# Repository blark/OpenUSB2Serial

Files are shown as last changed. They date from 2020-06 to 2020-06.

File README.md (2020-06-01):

# OpenUSB2Serial

An open source USB to serial adapter based on the cheap CH340C IC.

You can get 3 of these boards [from Oshpark](https://oshpark.com/shared_projects/jZ18QKPG) for $5.35.

## BOM

The BOM is [here](/bom.csv) all passives are 805.

Sourcing parts:  
[USB-C connector](https://lcsc.com/product-detail/USB-Type-C_Korean-Hroparts-Elec-TYPE-C-31-M-12_C165948.html)  
[CH340C](https://lcsc.com/product-detail/USB-ICs_WCH-Jiangsu-Qin-Heng-CH340C_C84681.html)  
[AZ1117-3.3](https://lcsc.com/product-detail/Low-Dropout-Regulators-LDO_Diodes-Incorporated-AZ1117CH-3-3TRG1_C92102.html)

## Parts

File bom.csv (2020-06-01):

Ref | Qnty | Value | Cmp name | Footprint | Description | Vendor
C1, C3, | 2 | 0.1uF | C_Small | Capacitor_SMD:C_0805_2012Metric | Unpolarized capacitor, small symbol
C2, C5, | 2 | 10uF | C_Small | Capacitor_SMD:C_0805_2012Metric | Unpolarized capacitor, small symbol
C4, | 1 | 22uF | C_Small | Capacitor_SMD:C_0805_2012Metric | Unpolarized capacitor, small symbol
C6, | 1 | 10nF | C_Small | Capacitor_SMD:C_0805_2012Metric | Unpolarized capacitor, small symbol
J1, | 1 | SERIAL | Conn_01x07 | Connector_PinHeader_2.54mm:PinHeader_1x07_P2.54mm_Vertical | Generic connector, single row, 01x07, script generated (kicad-library-utils/schlib/autogen/connector/)
J2, | 1 | USB_C_Receptacle_USB2.0 | USB_C_Receptacle_USB2.0 | Connector_USB:USB_C_Receptacle_HRO_TYPE-C-31-M-12 | USB 2.0-only Type-C Receptacle connector
JP1, | 1 | VSEL | SolderJumper_3_Open | Jumper:SolderJumper-3_P2.0mm_Open_TrianglePad1.0x1.5mm | Solder Jumper, 3-pole, open
R1, R2, | 2 | 5.1k | R_Small | Resistor_SMD:R_0805_2012Metric | Resistor, small symbol
U1, | 1 | CH340C | CH340G | Package_SO:SOIC-16_3.9x9.9mm_P1.27mm | USB serial converter, UART, SOIC-16
U2, | 1 | AZ1117-3.3 | AZ1117-3.3 | Package_TO_SOT_SMD:SOT-223 | 1A 20V Fixed LDO Linear Regulator, 3.3V, SOT-89/SOT-223/TO-220/TO-252/TO-263

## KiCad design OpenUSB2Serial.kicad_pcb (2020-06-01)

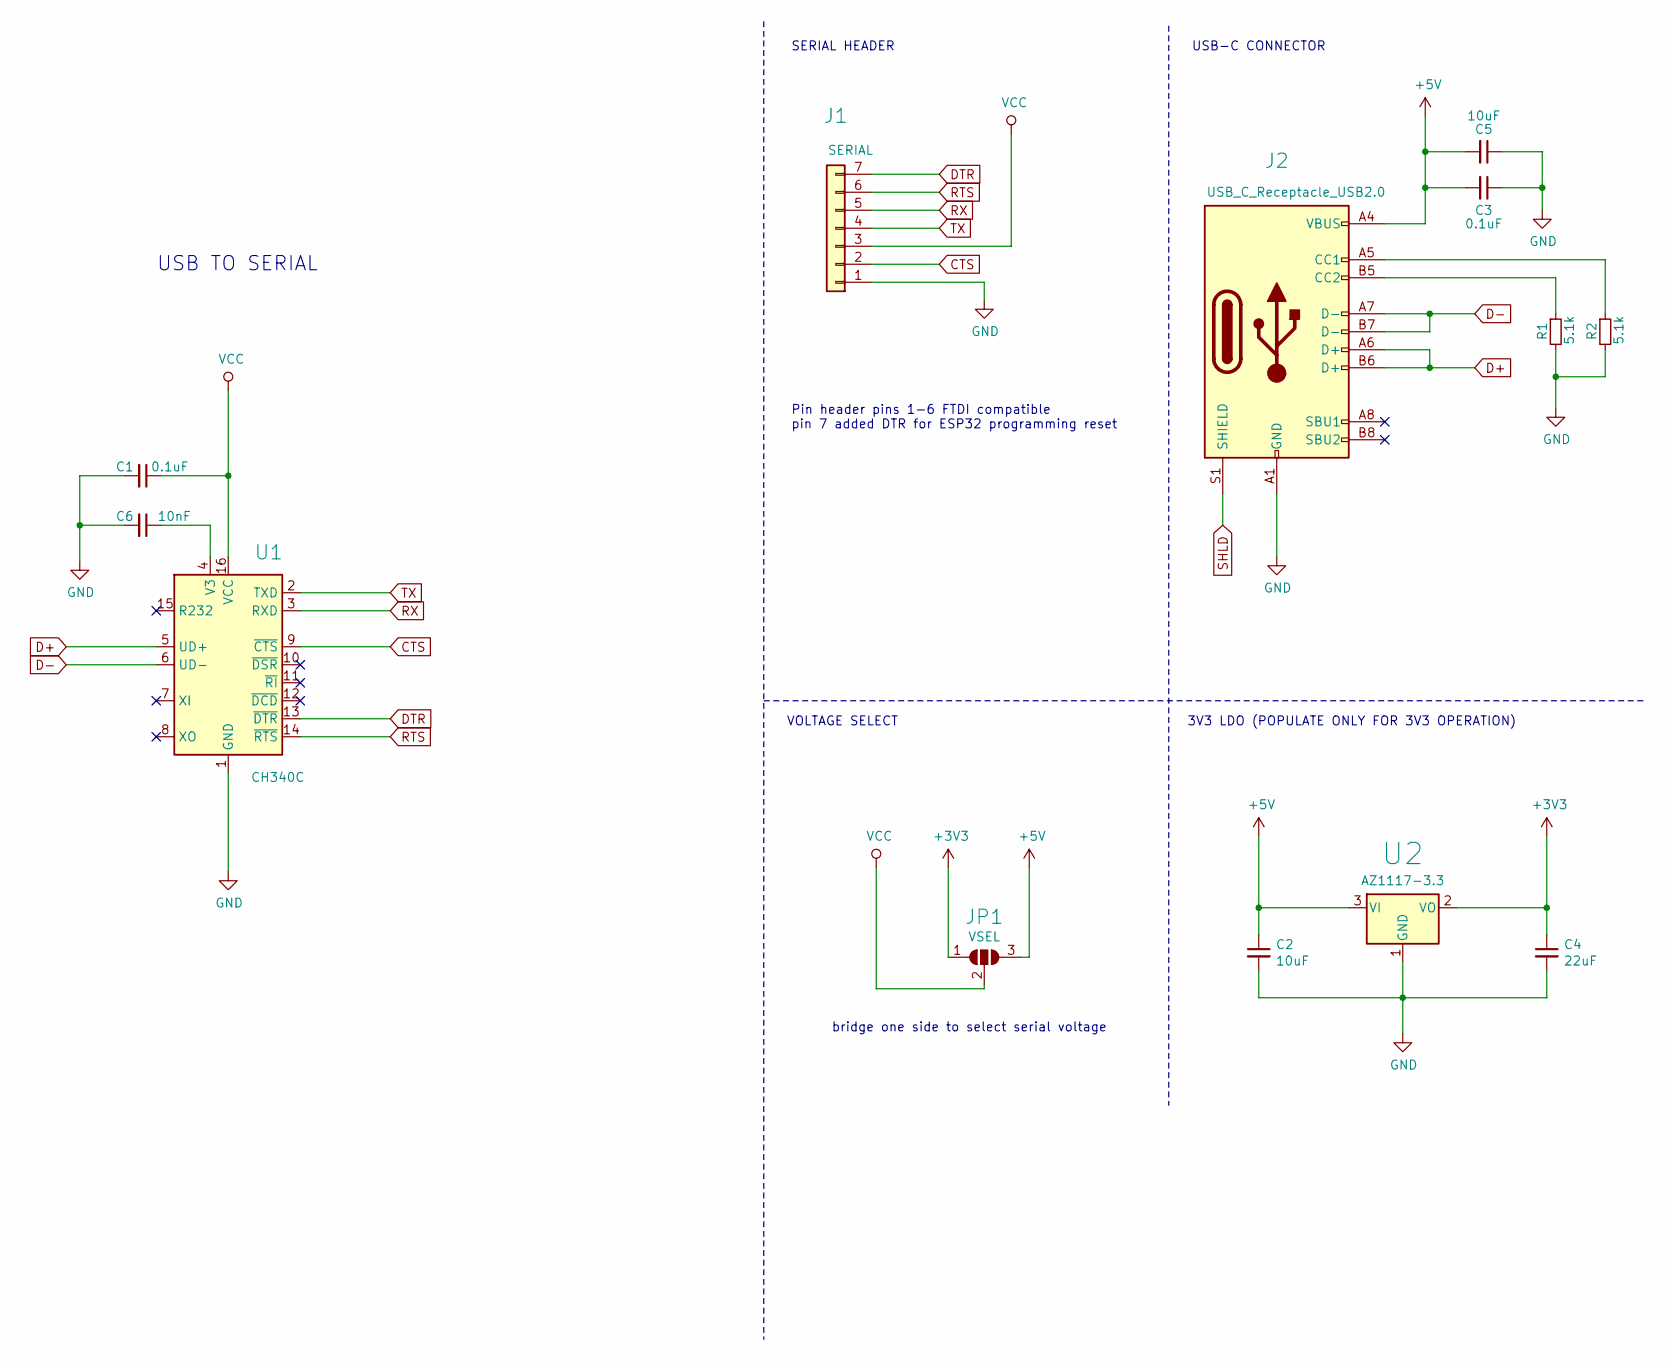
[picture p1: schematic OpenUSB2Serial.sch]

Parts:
C1, C3: 0.1uF; C_0805_2012Metric
C2, C5: 10uF; C_0805_2012Metric
C4: 22uF; C_0805_2012Metric
C6: 10nF; C_0805_2012Metric
J1: SERIAL; PinHeader_1x07_P2.54mm_Vertical
J2: USB_C_Receptacle_USB2.0; USB_C_Receptacle_HRO_TYPE-C-31-M-12
JP1: VSEL; SolderJumper-3_P2.0mm_Open_TrianglePad1.0x1.5mm
R1, R2: 5.1k; R_0805_2012Metric
U1: CH340C; SOIC-16_3.9x9.9mm_P1.27mm
U2: AZ1117-3.3; SOT-223

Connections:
+3V3: C4.1, JP1.1 (A), U2.2 (VO)
+5V: C2.1, C3.2, C5.2, J2.A4 (VBUS), J2.A9 (VBUS), J2.B4 (VBUS), J2.B9 (VBUS), JP1.3 (B), U2.3 (VI)
CTS: J1.2, U1.9 (~CTS)
D+: J2.A6 (D+), J2.B6 (D+), U1.5 (UD+)
D-: J2.A7 (D-), J2.B7 (D-), U1.6 (UD-)
DTR: J1.7, U1.13 (~DTR)
GND: C1.2, C2.2, C3.1, C4.2, C5.1, C6.2, J1.1, J2.A1 (GND), J2.A12 (GND), J2.B1 (GND), J2.B12 (GND), R1.2, R2.2, U1.1 (GND), U2.1 (GND)
unnamed: C6.1, U1.4 (V3)
unnamed: J2.A5 (CC1), R2.1
unnamed: J2.B5 (CC2), R1.1
RTS: J1.6, U1.14 (~RTS)
RX: J1.5, U1.3 (RXD)
SHLD: J2.S1 (SHIELD)
TX: J1.4, U1.2 (TXD)
VCC: C1.1, J1.3, JP1.2 (C), U1.16 (VCC)

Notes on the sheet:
3V3 LDO (POPULATE ONLY FOR 3V3 OPERATION)
USB-C CONNECTOR
USB TO SERIAL
Pin header pins 1-6 FTDI compatible pin 7 added DTR for ESP32 programming reset
SERIAL HEADER
VOLTAGE SELECT
bridge one side to select serial voltage

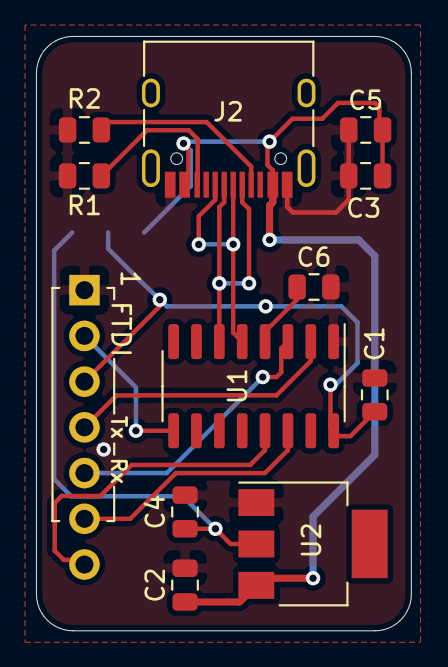
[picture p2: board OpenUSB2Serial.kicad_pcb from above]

Board: 2 copper layers, 20.8 x 33.0 mm, 13 parts (1 on the bottom side), 14 nets.
